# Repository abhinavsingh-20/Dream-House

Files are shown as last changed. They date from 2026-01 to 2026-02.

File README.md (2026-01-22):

# Dream-House

# Structural Analysis & Design of RC Multi-Story Building

## 📋 Project Overview
This project involves the structural analysis and design of a multi-story reinforced concrete building. The geometry and preliminary drafting were handled in **AutoCAD**, while the structural modeling, loading, and Finite Element Analysis (FEA) were performed using **Bentley STAAD.Pro**.

The structure is modeled as a 3D Space frame consisting of beam elements, column elements, and shell (plate) elements for slabs.

## 🛠️ Tools & Technologies
* **STAAD.Pro:** For structural modeling, load application, and stiffness matrix analysis.
* **AutoCAD:** For architectural planning and geometric drafting.

## 🏗️ Structural Specifications
Based on the input data (`autocad_project _Abhinav.std`), the structure possesses the following properties:

### Geometry & Materials
* [cite_start]**Structure Type:** Space Frame (3D) [cite: 1]
* [cite_start]**Material:** Isotropic Concrete [cite: 80]
    * [cite_start]Young's Modulus ($E$): $21.7 \times 10^6$ kN/m² [cite: 80]
    * [cite_start]Density: $23.56$ kN/m³ [cite: 80]
    * [cite_start]Concrete Strength ($f_{cu}$): $27,579$ kN/m² (approx M25/M30 grade) [cite: 80]
* [cite_start]**Support Conditions:** Fixed supports at the foundation level (Nodes 77-96)[cite: 80].

### Section Properties
| Element Type | Dimensions | Description | Source |
| :--- | :--- | :--- | :--- |
| **Beams** | 230mm x 230mm | [cite_start]Prismatic (0.23m x 0.23m) | [cite: 80] |
| **Columns** | 230mm x 230mm | [cite_start]Prismatic (0.23m x 0.23m) | [cite: 80] |
| **Slabs (Plates)** | 150mm | [cite_start]Thickness (0.15m) | [cite: 80] |

## 📉 Load Cases & Combinations
The structure is designed for the following load conditions:

### [cite_start]1. Dead Load (DL) [cite: 80]
* **Self-Weight:** Applied in the global Y-direction (-1 factor).
* [cite_start]**Wall/Member Loads:** * Uniform distributed load of **-14.72 kN/m** on main beams[cite: 81].
    * [cite_start]Uniform distributed load of **-4.6 kN/m** on secondary members[cite: 81].
* [cite_start]**Floor Finish/Dead Load:** Plate pressure of **-1.0 kN/m²**[cite: 80, 81].

### [cite_start]2. Live Load (LL) [cite: 81]
* [cite_start]**Floor Live Load:** Plate pressure of **-2.5 kN/m²** acting on shell elements[cite: 81].

### [cite_start]3. Load Combinations [cite: 81]
* **Ultimate Limit State:** `1.5 x Dead Load + 1.5 x Live Load`

## 📂 File Structure
```text
├── autocad_project _Abhinav.std    # Main STAAD.Pro Input File
├── autocad_project _Abhinav.dwg    # AutoCAD Geometry File (Optional)
└── README.md                       # Project Documentation

```
### 🚀 How to Run the Analysis

### 1. Clone the Repository
Open your terminal or command prompt and run the following command:

```bash
git clone [https://github.com/your-username/your-repo-name.git](https://github.com/your-username/your-repo-name.git)
```

### 2. Open in STAAD.Pro
1. Launch **STAAD.Pro Connect Edition**.
2. Navigate to the cloned folder.
3. Open the file: `autocad_project _Abhinav.std`.

### 3. Run Analysis
1. Go to the top menu: **Analysis** -> **Run Analysis**.
2. Once finished, check the Output file (`.ANL`) to verify the results and ensure there are no errors.

### 4. View Results
Switch to **Post-Processing** mode to visualize:
* **Displacement:** Nodal deflections.
* **Bending Moments:** Moment diagrams (Mz).
* **Shear Forces:** Shear diagrams (Fy).

---

## 📷 Visuals
* STAAD 3D Render
* AutoCAD Plan

---

## 👤 Author
**Abhinav**
*Civil/Structural Engineer*

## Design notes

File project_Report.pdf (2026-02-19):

## Indian Institute of Technology Mandi

### Kamand, Himachal Pradesh - 175075

# Design of Reinforced Concrete G+1 Residential Building

## CE 353P: Civil Engineering Drawing

### Academic Year 2025-26 (Odd Semester)

### Submitted by Group 1:

Role | Roll No. | Name
Member | B23059 | Abhinav Singh
Member | B23065 | Aman Raj Verma
Member | B23102 | Sumit Yadav

### Date of Submission: 26 November 2025

CE 353P: Civil Engineering Drawing | G+1 Residential Building Project

## Contents

1 Project Overview | 3
2 Architectural Design Phase | 3
3 Structural General Arrangement Phase | 10
4 Structural Analysis Phase | 11
5 Reinforced Concrete Design Phase | 15
6 Reinforcement Detailed Drawings | 24
7 Conclusion | 27

8 Key Insights and Learnings | 27
9 References | 28

## 1 Project Overview

The objective of this project is to plan, model, analyze, and design a G+1 residential building (”Dream Home”) in accordance with Indian Standard (IS) codes. The project encompasses Architectural Planning, Structural General Arrangement, Structural Analysis using STAAD.Pro, and detailed Reinforced Concrete (RC) Design.

## 2 Architectural Design Phase

### 2.1 Design Concept

The building is designed with functionality and aesthetics in mind, adhering to local building codes. The layout maximizes natural light and ventilation.

### 2.2 Architectural Drawings

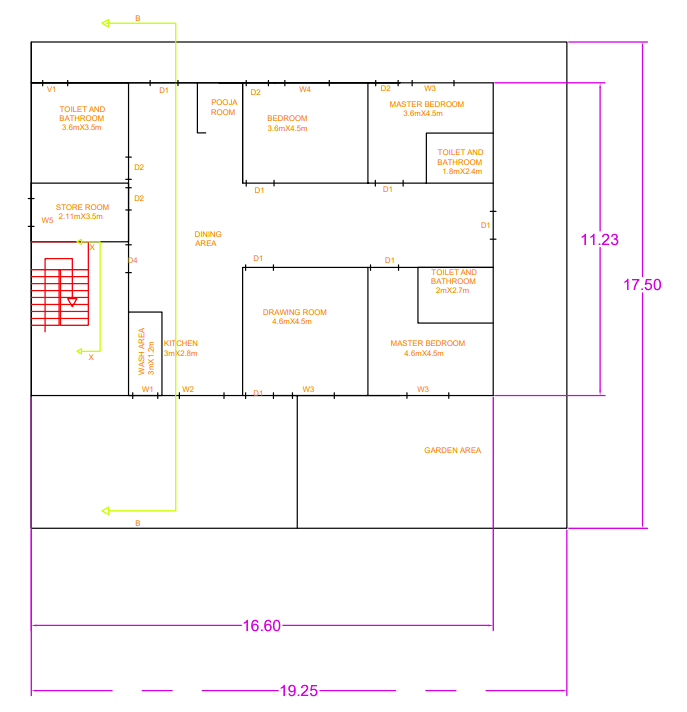
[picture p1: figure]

Figure 1: Ground Floor Line Plan

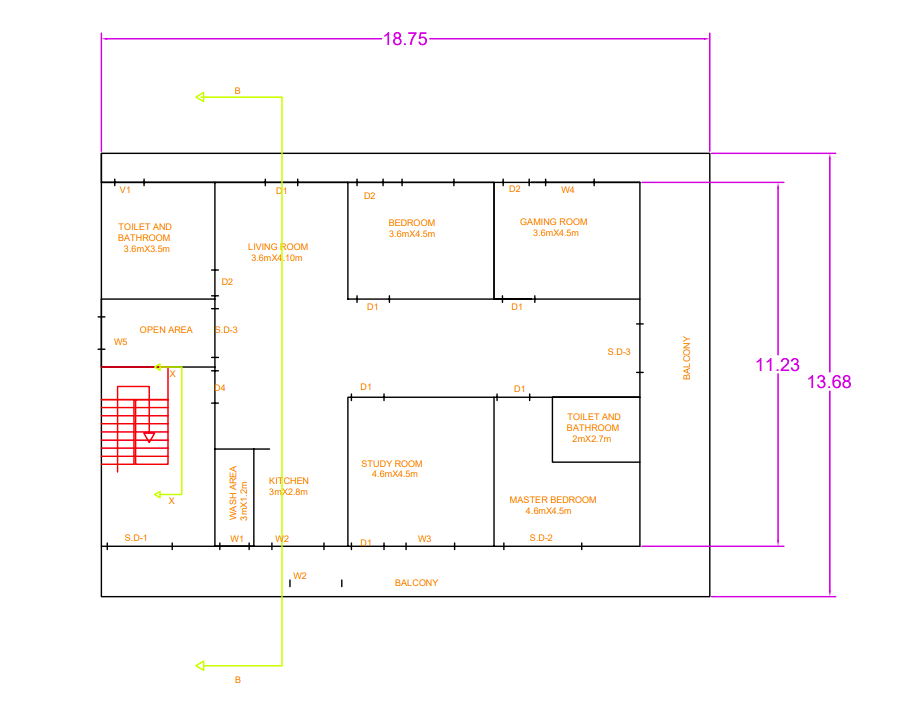
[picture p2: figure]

Figure 2: First Floor Line Plan

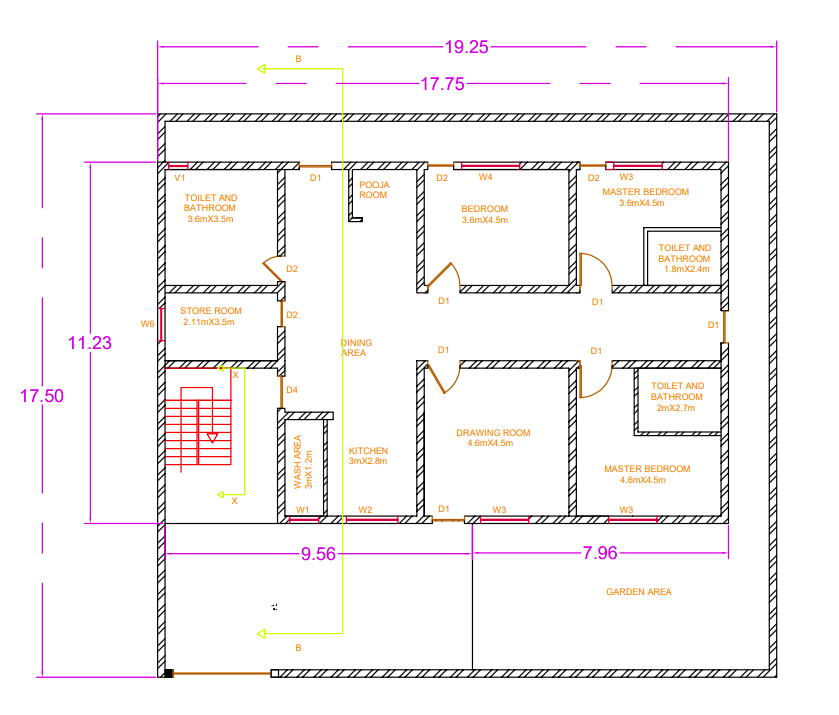
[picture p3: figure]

Figure 3: Ground Floor Architectural Plan

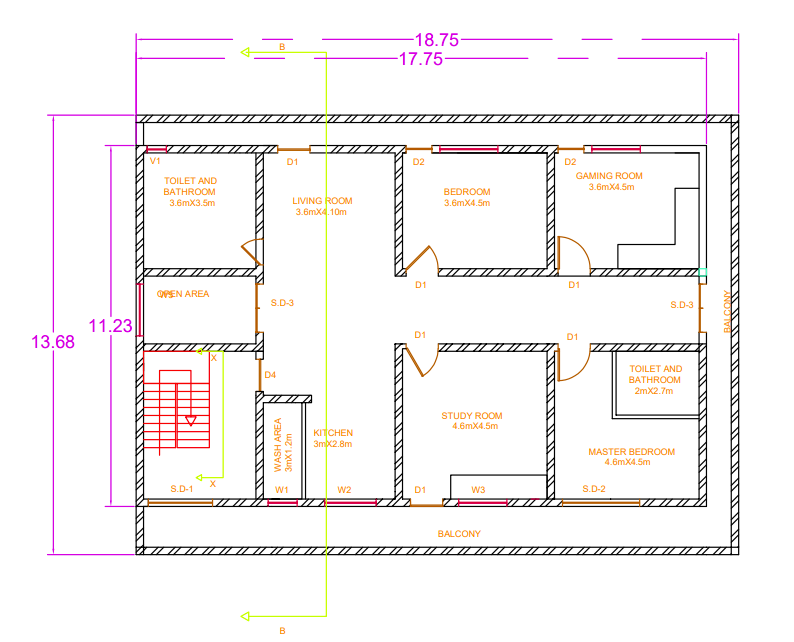
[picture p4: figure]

Figure 4: First Floor Architectural Plan

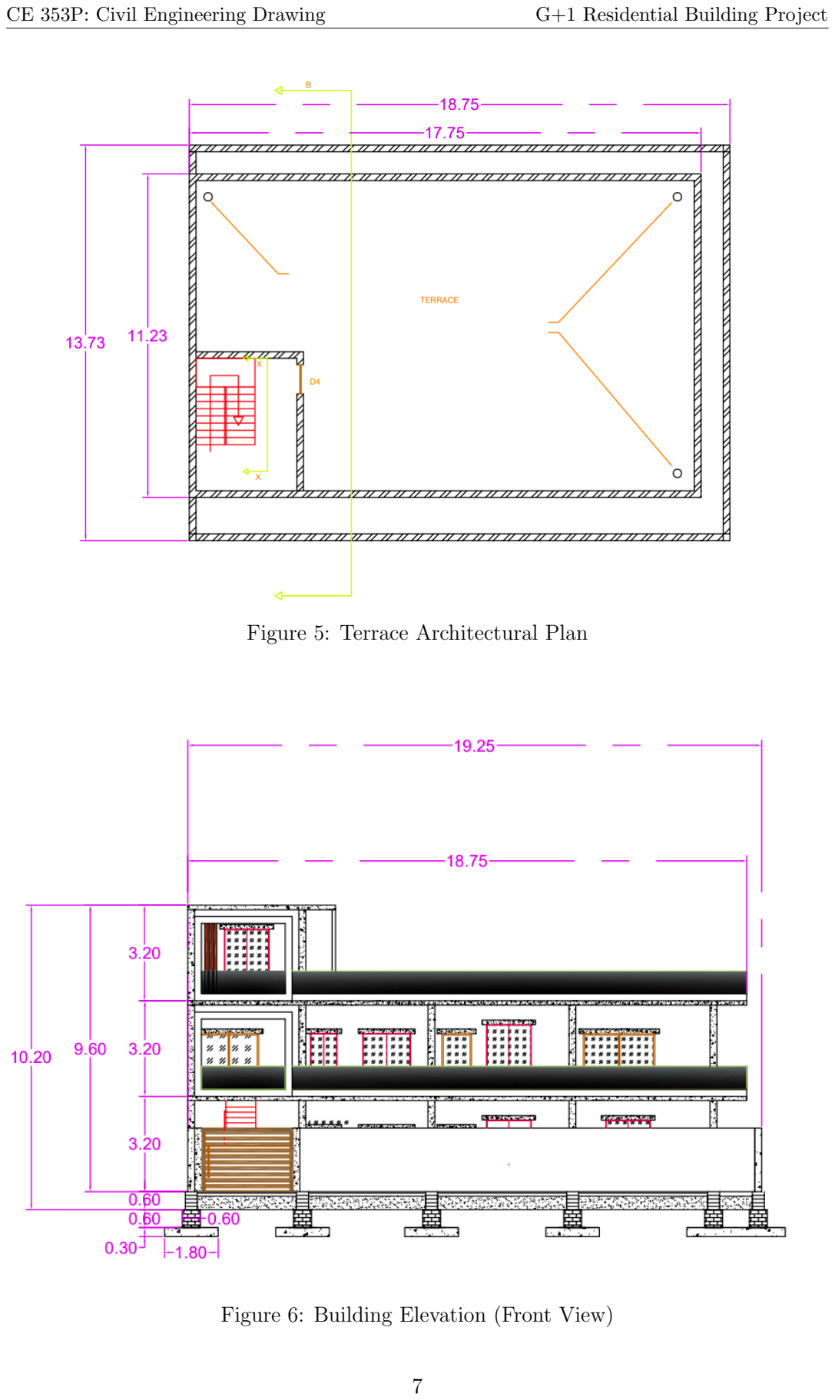
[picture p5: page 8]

Figure 5: Terrace Architectural Plan

Figure 6: Building Elevation (Front View)

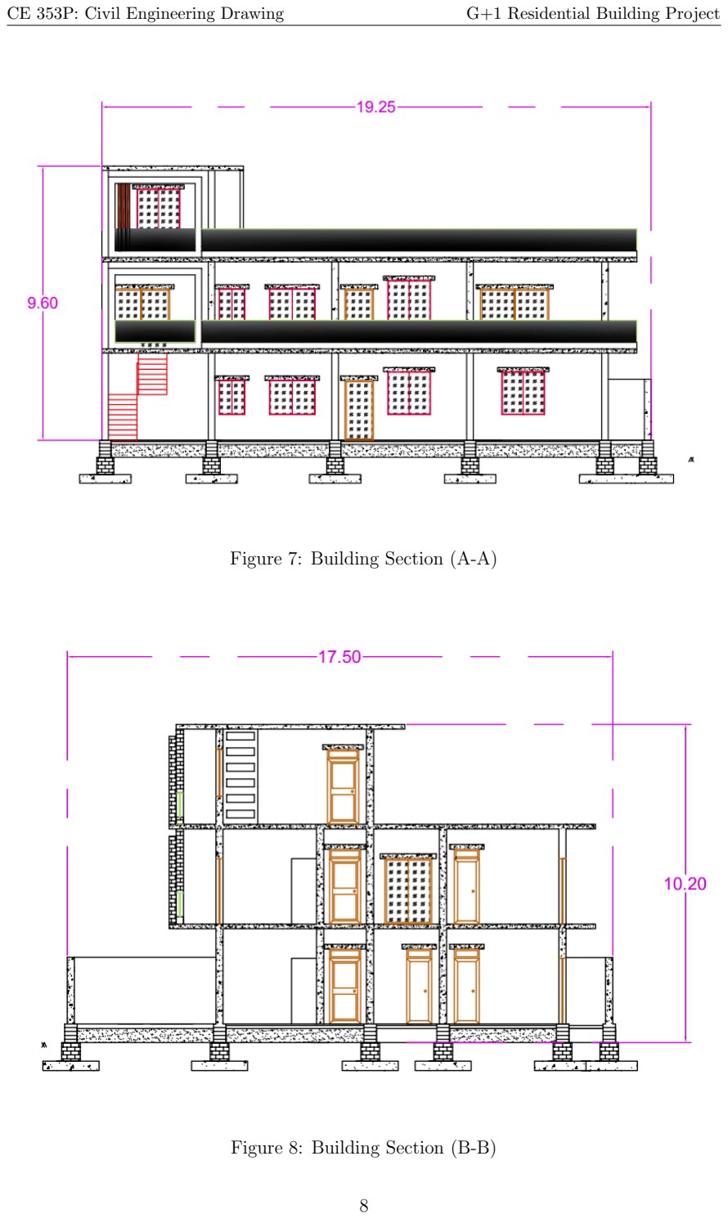
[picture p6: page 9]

Figure 7: Building Section (A-A)

Figure 8: Building Section (B-B)

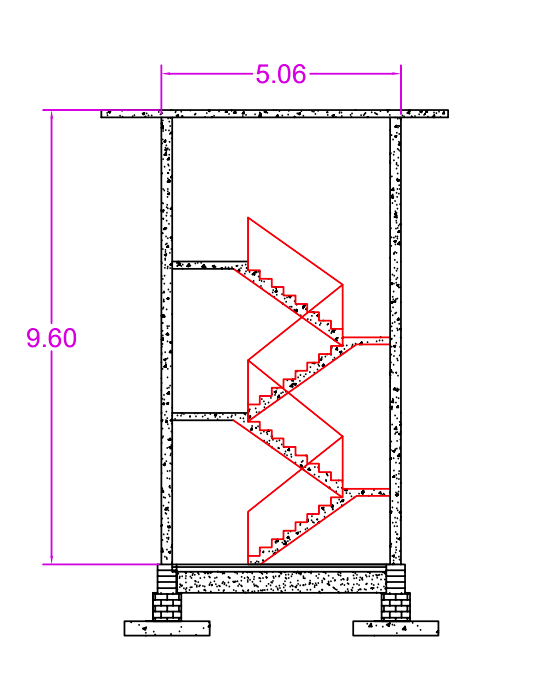
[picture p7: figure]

Figure 9: Staircase Section (X-X)

## 3 Structural General Arrangement Phase

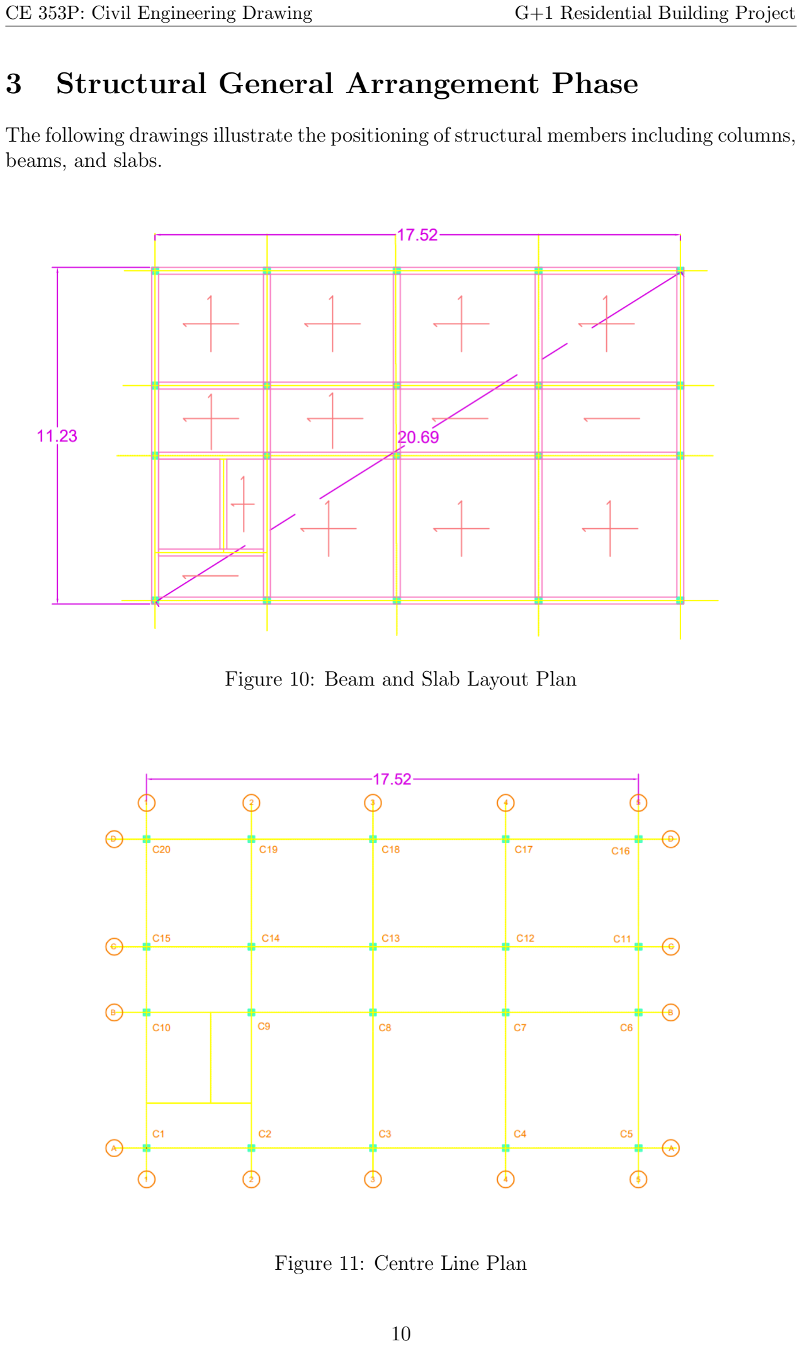
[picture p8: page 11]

The following drawings illustrate the positioning of structural members including columns, beams, and slabs.

Figure 10: Beam and Slab Layout Plan

Figure 11: Centre Line Plan

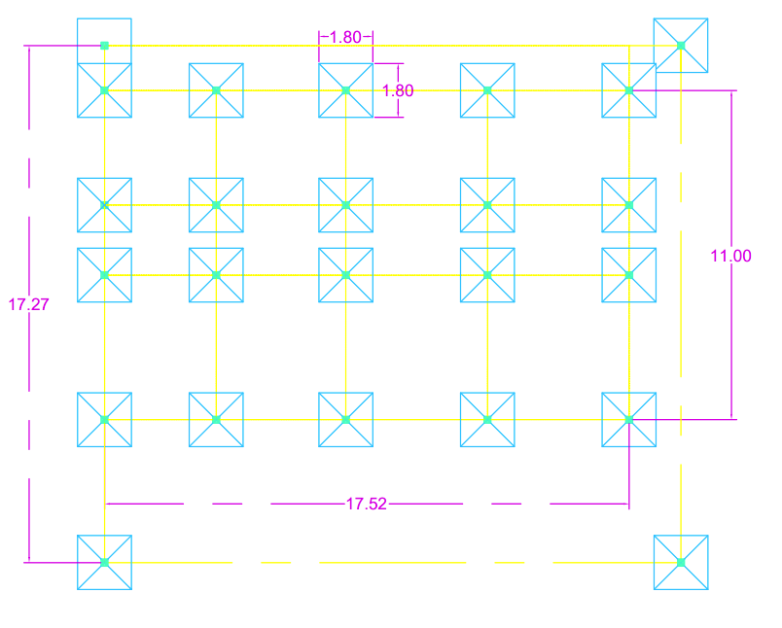
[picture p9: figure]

Figure 12: Foundation Layout

## 4 Structural Analysis Phase

The structure was modeled and analyzed using STAAD.Pro.

- Load Combination: 1.5 DL + 1.5 LL
- Frame Selected: The selected internal frame is marked by the node numbers and beam numbers as shown in the following diagrams. Similarly the beam, column, and the slab which have to be designed are represented by their respective nodes and element numbers.

– Selected Beam: Continuous beam joining the beams 19, 20, 21 and 22 (using the maximum span and end moments of the beam 21).

– Selected Column: Beam 27

– Selected Slab: Plate 136

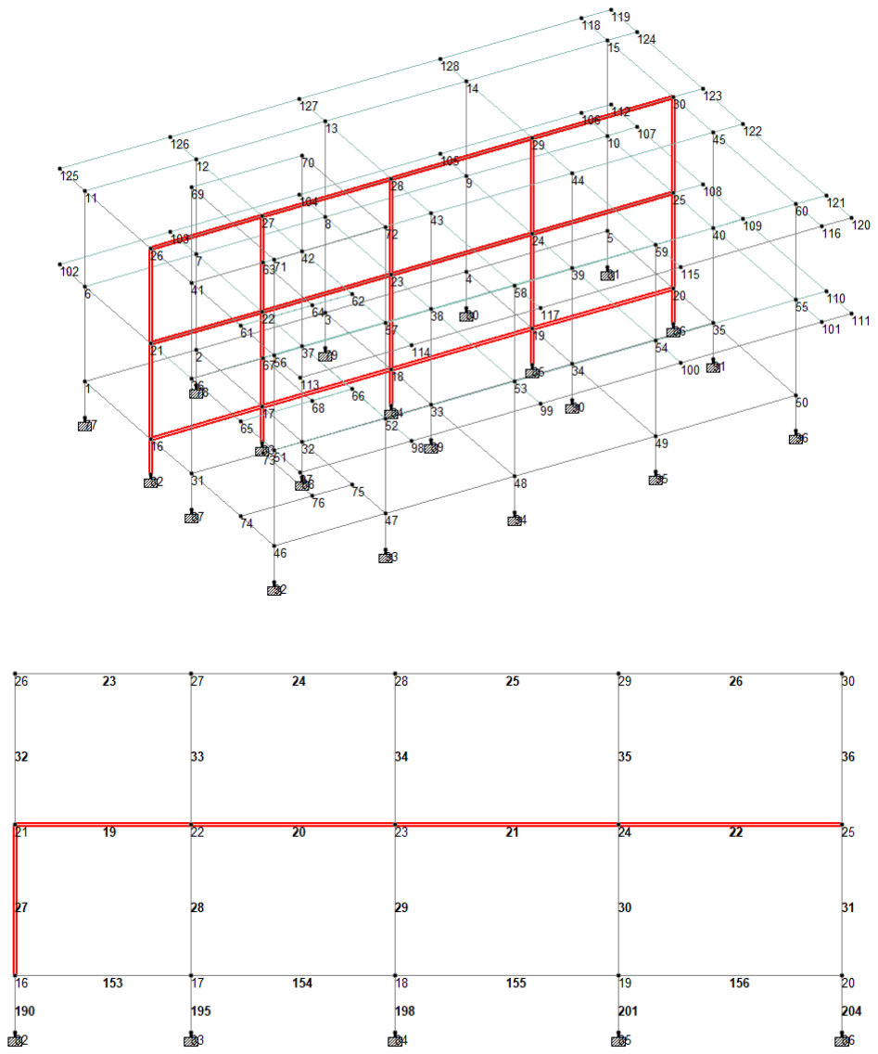
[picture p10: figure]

Figure 13: Selected Internal Frame in STAAD.Pro (top), Selected Beam and Column in the Internal Frame (bottom)

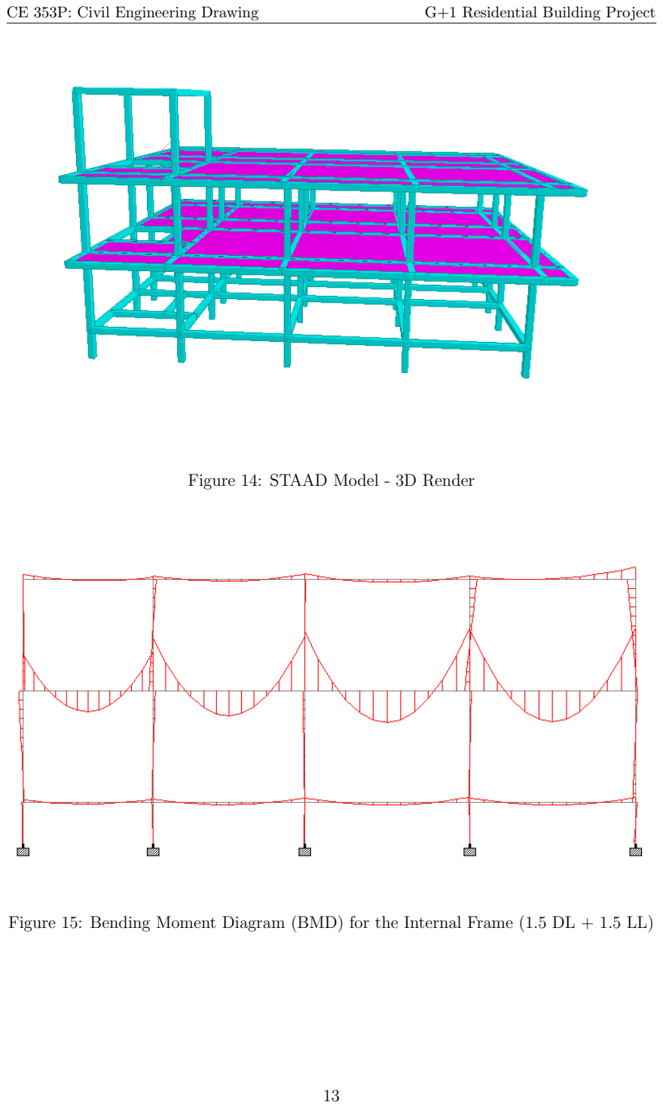
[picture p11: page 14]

Figure 14: STAAD Model - 3D Render

Figure 15: Bending Moment Diagram (BMD) for the Internal Frame (1.5 DL + 1.5 LL)

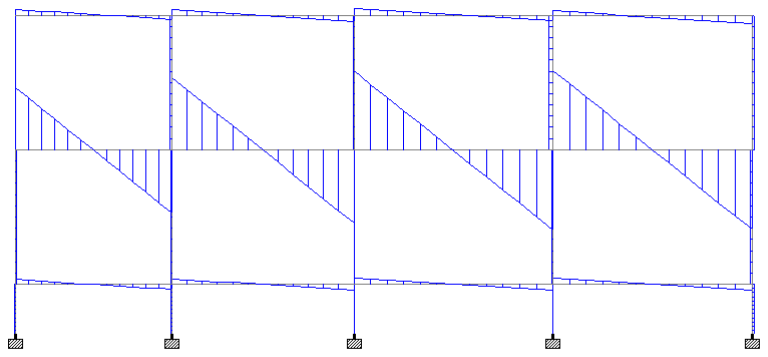
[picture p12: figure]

Figure 16: Shear Force Diagram (SFD) for the Internal Frame (1.5 DL + 1.5 LL)

## 5 Reinforced Concrete Design Phase

Note: The detailed structural design calculations presented in this section are based on the forces and moments extracted from STAAD.Pro model of our structure.

### 5.1 Design of Continuous Beam (First Floor)

5.1.1 1. Design Data & Properties

- Span (Center to Center): 4.73 m
- Cross Section (b × D): 230 mm × 230 mm
- Concrete Grade: M25 (fck = 25 N/mm² )
- Steel Grade: Fe500 (fy = 500 N/mm²
)
- Factored Forces:

– Max Support Moment (Mu,supp): 45.443 kNm (Hogging)

– Max Span Moment (Mu,span): 22.740 kNm (Sagging)

– Max Shear Force (Vu): 57.150 kN

- Effective Depth Calculation:

– Nominal Cover: 25 mm

– Stirrup Diameter: 8 mm

– Main Bar Diameter (Assumed max): 20 mm

– d = 230 − 25 − 8 −

20
2 = 187 mm

5.1.2 2. Limiting Moment Capacity Check

Determining if the section requires double reinforcement. Limiting Moment (Mu,lim) for Fe500:
Mu,lim = 0.133fckbd²

Mu,lim = 0.133 × 25 × 230 × 187²

Mu,lim = 26.74 × 10⁶ Nmm = 26.74 kNm

Check:

- Mu,supp(45.44) > Mu,lim(26.74) ⇒ Doubly Reinforced Section Required at Support.
- Mu,span(22.74) < Mu,lim(26.74) ⇒ Singly Reinforced Section Sufficient at Span.

5.1.3 3. Support Design (Hogging Moment)

Moment: 45.443 kNm (Tension at Top)
A. Excess Moment Calculation
Moment to be resisted by compression steel and additional tension steel:

Mu2 = Mu,supp − Mu,lim

Mu2 = 45.443 − 26.74 = 18.70 kNm

B. Tension Reinforcement (Ast) - Top

Total Ast = Ast1 + Ast2

Ast1 (for Mu,lim):

Ast1 =

Mu,lim
0.87fy(d − 0.42xu,max)

≈

26.74 × 10⁶
0.87 × 500 × 0.79 × 187

= 416 mm²

Ast2 (for Mu2):
Assume effective cover to compression steel (d

′
) = 40 mm.

Ast2 =

Mu2
0.87fy(d − d

′
)

=

18.70 × 10⁶
0.87 × 500 × (187 − 40) = 292 mm²

Total Required Ast: 416 + 292 = 708 mm² Provide: 2 Nos. 20mm ϕ + 1 No. 12mm ϕ
Area Provided: 628 + 113 = 741 mm²
(Safe).
C. Compression Reinforcement (Asc) - Bottom Strain Ratio (d

′/d): 40/187 = 0.21
Stress in Steel (fsc): From SP16 for Fe500 at d

′/d = 0.2, fsc = 353 N/mm² .
Required Area:

Asc =

Mu2

fsc(d − d

′
)

=

18.70 × 10⁶
353 × 147

= 360 mm²

Provide: 2 Nos. 16mm ϕ
Area Provided: 402 mm²
(Safe).
Note: These bars will extend into the span to serve as main tensile reinforcement for the sagging moment.

5.1.4 4. Mid-Span Design (Sagging Moment)

Moment: 22.740 kNm (Tension at Bottom)
Required Ast:
Since Mu < Mu,lim, use singly reinforced formula (approximate):

Ast =

Mu
0.87fy(0.9d)

=

22.74 × 10⁶
0.87 × 500 × 0.9 × 187

= 310 mm²

Check Minimum Steel (IS 456 Cl 26.5.1.1):

Ast,min =

0.85bd
fy

=

0.85 × 230 × 187
500

= 73 mm²

(Check Passed)
Provide: 2 Nos. 16mm ϕ (Bottom)
Area Provided: 402 mm²
Note: This matches the compression steel required at supports, ensuring continuity.

5.1.5 5. Shear Reinforcement Design

Factored Shear (Vu): 57.150 kN
Nominal Shear Stress (τv):

τv =

Vu
bd =

57150
230 × 187

= 1.33 N/mm²

τc,max for M25 = 3.1 N/mm²
. Since τv < τc,max, section size is OK. Concrete Shear Strength (τc): Percentage of steel at support tension zone (pt):

pt =

100Ast,prov
bd =

100 × 741
230 × 187

= 1.72%

From IS 456 Table 19 (M25): τc ≈ 0.76 N/mm² Shear Reinforcement Calculation: Since τv > τc, shear reinforcement is required. Shear taken by stirrups (Vus):

Vus = Vu − τcbd = 57150 − (0.76 × 230 × 187) = 24463 N

Spacing (sv) for 2-legged 8mm Stirrups (Asv = 100 mm² ):

sv =

0.87fyAsvd

Vus

= | 0.87 × 500 × 100 × 187
24463

= 332 mm

Maximum Spacing Criteria:

- 0.75d = 0.75 × 187 = 140 mm
- 300 mm
- Calculated (332 mm)

Adopt: 130 mm c/c (rounded down for safety).

5.1.6 6. Development Length (Ld)

Reference: IS 456 Cl 26.2.1
| Ld =

ϕσs
4τbd
σs = 0.87fy = 435 N/mm²
τbd (Bond stress for M25) = 1.4 N/mm²
For Deformed bars (Fe500), increase τbd by 60%: τbd,design = 2.24 N/mm²
Ld = | ϕ × 435
| 4 × 2.24

≈ 48.5ϕ

- 20mm Bars: Ld = 48.5 × 20 = 970 mm
- 16mm Bars: Ld = 48.5 × 16 = 776 mm
- 12mm Bars: Ld = 48.5 × 12 = 582 mm

5.1.7 7. Deflection Check (Serviceability)

Reference: IS 456 Cl 23.2.1
Basic L/d ratio for continuous beam = 26. Actual L/d ratio = 4730/187 = 25.29.
25.29 < 26 ⇒ Safe against deflection.

5.1.8 8. Final Schedule of Reinforcement

Location | Reinforcement | Remarks
Support Top | 2-20ϕ + 1-12ϕ | Extend 970 mm into span
Span Bottom | 2-16ϕ | Continuous throughout
Support Bottom | 2-16ϕ | Same as Span Bottom
Shear Stirrups | 8mm ϕ @ 130mm c/c | 2-Legged

### 5.2 Design of Ground Floor Column

5.2.1 1. Design Data & Properties

- Column Dimensions (b × D): 230 mm × 230 mm
- Unsupported Length (L): 3.20 m = 3200 mm
- Material Properties:

– Concrete Grade (fck): 25 N/mm²
(M25)
– Steel Grade (fy): 500 N/mm² (Fe 500)
- Loads (Factored):

– Axial Load (Pu): 219.363 kN

– Applied Moment (Mux): 0.515 kNm

– Applied Moment (Muy): 2.901 kNm

5.2.2 2. Step 1: Slenderness Check

First, we determine if the column is ”Short” or ”Slender” (Long). Assuming the column is effectively held in position at both ends but not restrained against rotation (hinged-hinged).
lef f ≈ 1.0 × L = 3200 mm

Slenderness Ratio (λ):

λ =

lef f
D

=

3200
230

= 13.91

According to IS 456 Cl. 25.1.2: Since λ > 12, this is a Slender (Long) Column. We must calculate additional moments due to deflection.

5.2.3 3. Step 2: Minimum Eccentricity & Design Moments

A. Minimum Eccentricity (emin)
According to Cl. 25.4:

emin =

L
500

+

D
30

=

3200
500

+

230
30

= 6.4 + 7.67 = 14.07 mm

Subject to a minimum of 20 mm. Therefore, emin = 20 mm.
B. Moments due to Minimum Eccentricity

Mmin = Pu × emin = 219.363 kN × 0.020 m = 4.387 kNm

C. Check Governing Initial Moments The code requires we design for the greater of the Applied Moment or Mmin.
- Mux,applied = 0.515 kNm < 4.387 kNm. Use 4.387 kNm.
- Muy,applied = 2.901 kNm < 4.387 kNm. Use 4.387 kNm.
D. Additional Moments (Due to Slenderness) Since it is a slender column, we add Madd (Cl. 39.7.1):

Madd =

PuD

2000
lef f
D

2

Madd =

219.363 × 0.230
2000

× (13.91)²

Madd = 0.0252 × 193.49 = 4.88 kNm

E. Total Design Moments (Mu)

Mux = Mmin + Madd = 4.387 + 4.88 = 9.267 kNm

Muy = Mmin + Madd = 4.387 + 4.88 = 9.267 kNm

Summary of Design Loads: Pu = 219.363 kN, Mux = 9.27 kNm, Muy = 9.27 kNm

5.2.4 4. Step 3: Longitudinal Reinforcement

A. Check Required Steel Percentage
Check non-dimensional parameters to see if Minimum Steel controls. Cover (d

′
) = 40mm
(nominal) + 8mm (link) + 6mm (center of bar) ≈ 54mm. d

′/D ≈ 0.2.

Pu
fckbD =

219.363 × 10³
25 × 230 × 230

= 0.166

Mu

fckbD²

=

9.27 × 10⁶
25 × 230 × 230²

= 0.030

These values are very low. Even with minimum steel, the capacity will be much higher than required.
B. Provide Minimum Steel
According to Cl. 26.5.3.1: Minimum steel = 0.8% of Gross Area (Ag).

Asc,min =

0.8
× 230 × 230 = 423.2 mm²

Trial: Provide 4 bars of 12 mm diameter.

Asc,provided = 4 ×

π
4

(12)² = 4 × 113 = 452 mm²

452 > 423.2 (Safe)

Percentage provided (p) = 0.85%

5.2.5 5. Step 4: Check for Biaxial Safety (Cl. 39.6)

We must ensure the section passes the interaction check:
Mux

Mux1

αn
+
Muy

Muy1

αn
≤ 1.0
A. Calculate Puz (Pure Axial Capacity)

Puz = 0.45fckAc + 0.75fyAsc

Ac = 52900 − 452 = 52448 mm²

Puz = (0.45 × 25 × 52448) + (0.75 × 500 × 452)

Puz = 590040 + 169500 = 759540 N = 759.54 kN
B. Calculate αn exponent Ratio Pu
Puz

=

219.363
759.54 = 0.288. Since the ratio is between 0.2 and 0.8:
αn = 1.0 +

0.288 − 0.2
0.8 − 0.2

(2.0 − 1.0) = 1.0 +

0.088
0.6

= 1.15

C. Determine Uniaxial Moment Capacity (Mu1) Using SP:16 Charts (Chart 44 for Fe 500, d’/D=0.2): Pu/fckbD = 0.166, p/fck = 0.85/25 = 0.034. From chart:

Mu1
fckbD² ≈ 0.09.

Mux1 = Muy1 = 0.09 × 25 × 230 × 230² = 27.38 kNm

D. Interaction Check
9.27

27.381.15
+
9.27

27.381.15

(0.338)¹.15 + (0.338)¹.15 = 0.286 + 0.286 = 0.572 ≤ 1.0

Result: The section is SAFE in biaxial bending.

5.2.6 6. Step 5: Transverse Reinforcement (Lateral Ties)

A. Diameter of Links (Cl. 26.5.3.2)
Greater of: 1
4 × 12 = 3 mm or 6 mm. Use 8 mm diameter ties.
B. Pitch (Spacing) of Links Least of:
1. Least Lateral Dimension = 230 mm
2. 16 × Smallest Long. Bar = 16 × 12 = 192 mm
3. 300 mm

Result: Provide 8 mm ϕ ties @ 190 mm c/c.

### 5.3 Design of Slab Panel (First Floor)

5.3.1 1. Design Constants & Parameters

- Concrete: M25 (fck = 25 N/mm²
)
- Steel: Fe415 (fy = 415 N/mm²
)
- Unit Weight of Concrete: 25 kN/m³
- Dimensions (Center to Center):

– Lx = 4.73 m (Shorter Span)

– Ly = 4.83 m (Longer Span)

- Aspect Ratio:

r =

Ly
Lx

=

4.83
4.73

= 1.02

Since Ly
Lx

< 2, it is designed as a Two-Way Slab.

5.3.2 2. Depth & Effective Span

- Overall Depth (D): 150 mm
- Nominal Cover: 20 mm (Mild Exposure)
- Assumed Bar Diameter (ϕ): 10 mm
- Effective Depth (d):

– Short Span (dx): D − Cover −

ϕ
2 = 150 − 20 − 5 = 125 mm

– Long Span (dy): dx − ϕ = 125 − 10 = 115 mm

5.3.3 3. Load Calculations

- Dead Load (DL):

– Self Weight: 0.150 × 25 = 3.75 kN/m²

– Floor Finish: 1.00 kN/m²

– Total DL: 4.75 kN/m²

- Live Load (LL): 2.50 kN/m²
- Total Design Load (wu):

wu = 1.5 × (4.75 + 2.50) = 1.5 × 7.25 = 10.875 kN/m²

5.3.4 4. Bending Moments (IS 456 Table 26)

Condition: Two Adjacent Edges Discontinuous (Case 4). Ratio = 1.02.

- Short Span Neg. (α
−
x

): 0.0482

- Short Span Pos. (α
+
x

): 0.0360

- Long Span Neg. (α
−
y

): 0.0470

- Long Span Pos. (α
+
y

): 0.0350

Constant Factor (K) = 10.875 × 4.73² = 243.29
Moments:
- Mu,x (Negative - Support): 0.0482 × 243.29 = 11.73 kNm
- Mu,x (Positive - Midspan): 0.0360 × 243.29 = 8.76 kNm
- Mu,y (Negative - Support): 0.0470 × 243.29 = 11.43 kNm
- Mu,y (Positive - Midspan): 0.0350 × 243.29 = 8.51 kNm

5.3.5 5. Check for Effective Depth

Check required depth for Mu,max = 11.73 kNm.

Mu,lim = 0.138fckbd²

11.73 × 10⁶ = 0.138 × 25 × 1000 × d

2
req
dreq = 58.3 mm

Check: dprovided(125 mm) > dreq(58.3 mm) ⇒ SAFE.

5.3.6 6. Reinforcement Design

Minimum Steel: Ast,min = 0.12% of bD = 180 mm² .
Formula: Ast ≈

Mu
0.87fy(0.9d)
A. Short Span Reinforcement (Along 4.73m)
- Continuous Edge (Top): Mu = 11.73 kNm

Ast = 289 mm² ⇒ Provide: 10mm ϕ @ 270 mm c/c

- Mid-Span (Bottom): Mu = 8.76 kNm

Ast = 216 mm² ⇒ Provide: 8mm ϕ @ 230 mm c/c

B. Long Span Reinforcement (Along 4.83m) (Use d = 115mm)
- Continuous Edge (Top): Mu = 11.43 kNm

Ast = 305 mm² ⇒ Provide: 10mm ϕ @ 250 mm c/c

- Mid-Span (Bottom): Mu = 8.51 kNm

Ast = 227 mm² ⇒ Provide: 8mm ϕ @ 220 mm c/c

5.3.7 7. Check for Shear

Max Shear (Vu): 0.5 × wu × Lx = 25.72 kN.

τv =

25.72 × 1000
1000 × 125

= 0.21 N/mm²

Permissible Shear (τc): M25, low steel % + Slab Factor 1.3 = 0.39 N/mm² . Result:
τv < τc ⇒ Shear is SAFE.

5.3.8 8. Check for Deflection

Actual L/d = 4730/125 = 37.8. Allowable = Basic (26) ×kt(1.6) = 41.6. Result: 37.8 < 41.6 ⇒ Deflection is SAFE.

5.3.9 9. Torsion Reinforcement (Corners)

Mesh Size: Lx/5 = 950 mm.

- Discontinuous Corner: Provide 4 layers. Area = 0.75Ast,max = 162 mm² . Provide 8mm ϕ @ 200 mm c/c mesh.
- Other Corners: Provide minimum mesh 8mm ϕ @ 200 mm c/c.

5.3.10 10. Final Summary of Slab Design

Component | Details
Slab Thickness | 150 mm (M25 / Fe415)
Short Span (Bottom) | 8mm @ 230 mm c/c
Short Span (Top @ Support) | 10mm @ 270 mm c/c
Long Span (Bottom) | 8mm @ 220 mm c/c
Long Span (Top @ Support) | 10mm @ 250 mm c/c
Corner Mesh | 8mm @ 200 mm c/c (950x950mm)

## 6 Reinforcement Detailed Drawings

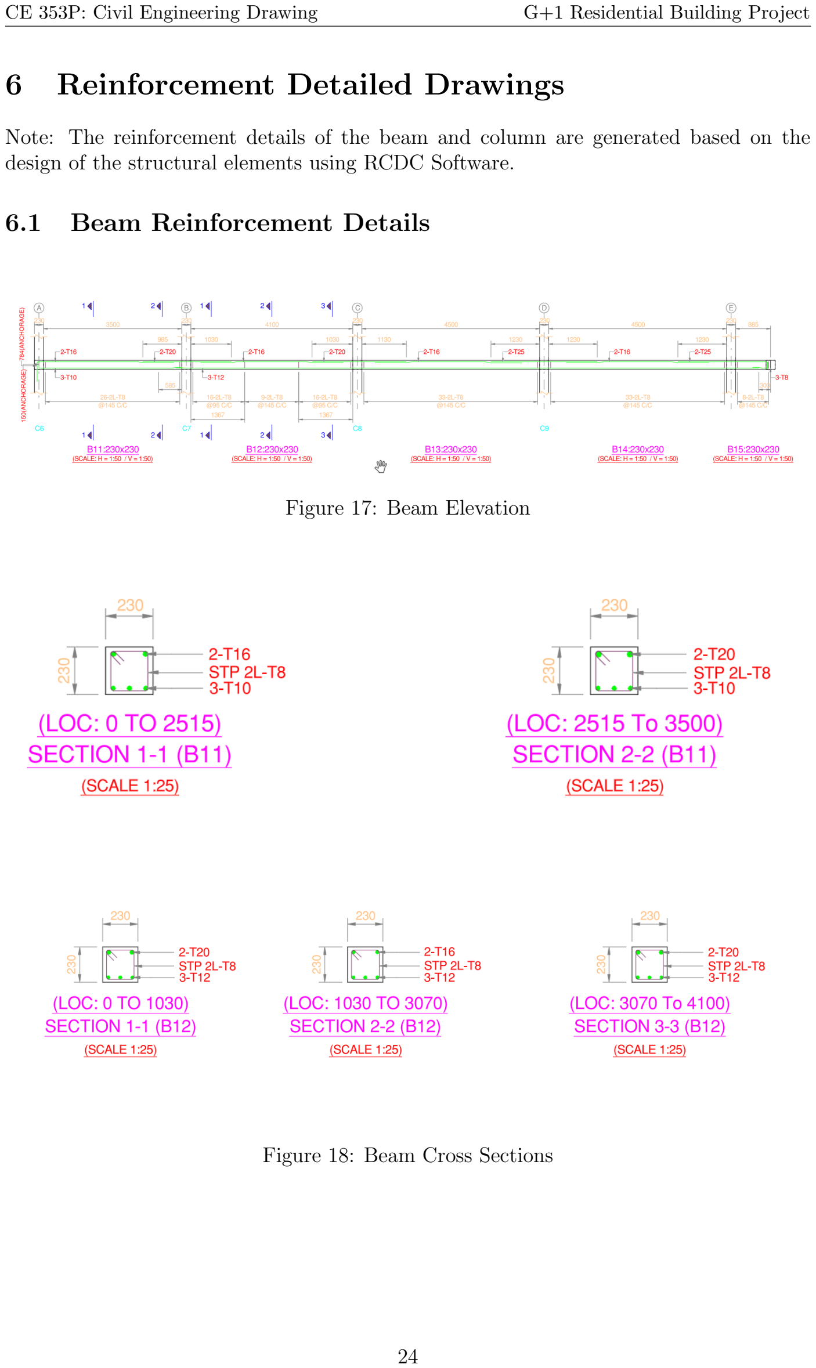
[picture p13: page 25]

Note: The reinforcement details of the beam and column are generated based on the design of the structural elements using RCDC Software.

### 6.1 Beam Reinforcement Details

Figure 17: Beam Elevation

Figure 18: Beam Cross Sections

### 6.2 Column Reinforcement Details

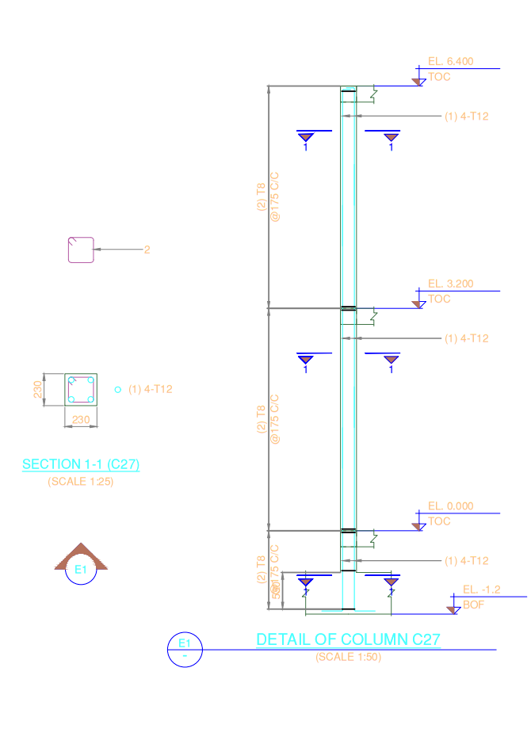
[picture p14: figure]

Figure 19: Columnn Elevation and Cross Section

### 6.3 Slab Reinforcement Details

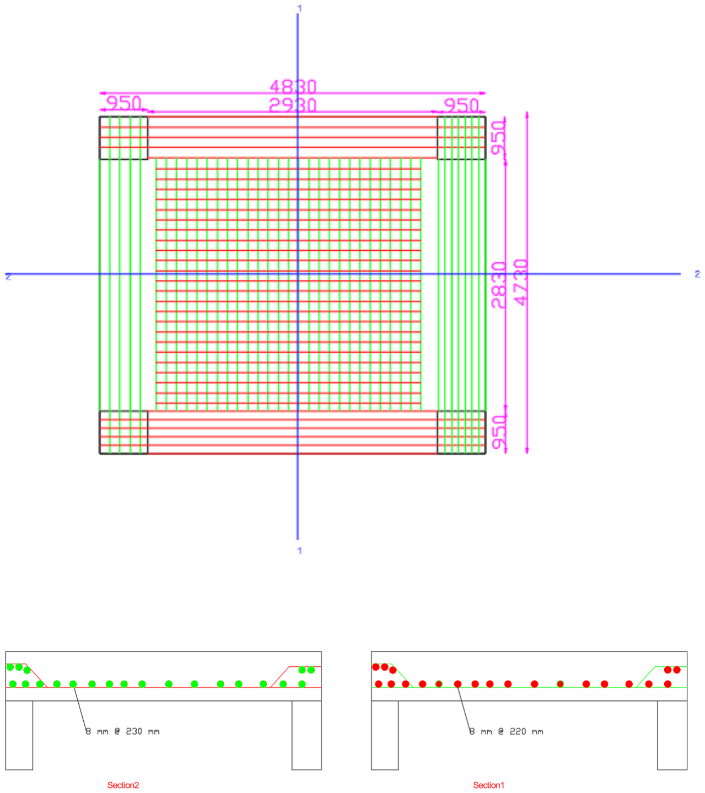
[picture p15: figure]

Figure 20: Slab Reinforcement Diagrams

## 7 Conclusion

The G+1 residential building was successfully designed using M25 concrete and Fe500/415 steel.

- The critical continuous beam required a doubly reinforced section at the supports due to high hogging moments.
- The columns were identified as slender due to their length-to-depth ratio and were designed for additional moments.
- The slab acted as a two-way slab and was safe in deflection and shear without shear reinforcement.

The design ensures safety, serviceability, and economy adhering to IS 456:2000 and SP:16.

## 8 Key Insights and Learnings

This project served as a comprehensive exercise in bridging the gap between theoretical structural engineering concepts and practical application. Through the design of the G+1 residential building, the group gained significant insights into the following areas:

- The Language of Civil Engineering: This course emphasized that drawings are the universal language of construction. We learned that precision in draft-ing—correct line weights, standard symbols, and clear dimensioning—is as critical as the design calculation itself to ensure errors are avoided during site execution.
- Translation of Theory to Practice: While theoretical courses taught us how to calculate reinforcement, this subject taught us where and how to place it. We gained a practical understanding of concepts like curtailment, development length, and cranking of bars, which are essential for monolithic structural behavior.
- Holistic Design Workflow: The subject provided a complete overview of the project lifecycle. We learned how to navigate the iterative process of moving from an Architectural Plan to a Structural General Arrangement (GA), and finally to detailed structural analysis and design.
- Navigating Indian Standards (IS Codes): We developed proficiency in using IS 456:2000, IS 875, and SP:16. We learned that these codes are not just rulebooks but frameworks for safety, teaching us how to balance economy with safety requirements in real-world scenarios.
- Visualization of Load Paths: Creating the structural drawings helped us vi-sualize how loads transfer from slabs to beams, beams to columns, and finally to the foundation. This visualization is crucial for intuition in structural engineering, preventing major conceptual errors in design.
- The Role of Computer-Aided Design: By combining manual calculations with software tools (like STAAD.Pro), we learned that while software ensures speed and handles complexity, manual design checks are indispensable for verifying accuracy and maintaining engineering control over the structure.

### 8.1 Contribution of Group Members

The successful completion of this project was a collaborative effort, with tasks distributed to leverage individual strengths. The specific contributions are detailed below:

Roll No. | Name | Key Contributions & Responsibilities
B23065 | Aman Raj Verma | Structural Design Lead • Performed detailed manual design calcula-tions for Beams, Columns, and Slabs. • Verified structural safety checks (Deflec-tion, Shear, and Bond). • Compiled the Design Calculation Sheets.
B23059 | Abhinav Singh | Architectural Planning & Modeling • Developed the Architectural Plans, Eleva-tions, and Sections. • Created the initial 3D model in STAAD.Pro. • Prepared the Building Line Plan.
B23102 | Sumit Yadav | Structural Analysis & Detailing • Executed the Structural Analysis (Load combinations and Force extraction). • Drafted the Structural General Arrange-ment (GA) drawings. • Prepared final Reinforcement Detailing drawings.

Table 1: Distribution of Work Responsibilities

## 9 References

1. IS 456:2000 - Plain and Reinforced Concrete - Code of Practice.
2. SP 16:1980 - Design Aids for Reinforced Concrete to IS 456.
3. IS 875 (Parts 1 & 2) - Code of Practice for Design Loads.
4. SP 34 - Handbook on Concrete Reinforcement and Detailing.

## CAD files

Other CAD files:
project_autocad_Abhinav.dwg
